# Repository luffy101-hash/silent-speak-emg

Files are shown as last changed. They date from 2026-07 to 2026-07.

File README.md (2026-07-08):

# SpeakEMG

> Silent-speech interface using multichannel surface EMG in over-ear headphones.

**Demo:** [luffy101-hash.github.io/SpeakEMG](https://luffy101-hash.github.io/SpeakEMG/) — interactive EMG simulator + command classifier

## What is this?

SpeakEMG reads facial and jaw muscle activity through four Grove EMG sensors mounted in headphone earmuffs. When you mouth words without sound, an ESP32-S3 streams 4-channel EMG data to a laptop, a 1D CNN classifies 3-second windows into one of 10 commands, and a companion app displays the result with text-to-speech.

Inspired by Tang et al., *IEEE TIM* 2025 (arXiv:2504.13921)

## Features

- 4-channel sEMG acquisition at 1000 Hz (ESP32-S3)
- 20 to 450 Hz Butterworth bandpass filtering
- 1D CNN classifier (10 silent commands)
- Real-time inference + TTS companion app
- Bench mode (USB serial) and wearable mode (Wi-Fi UDP)

## Commands

| Open | Close | Start | Stop | Yes |
|---|---|---|---|-----|
| No | Next | Back | Okay | Cancel |

## Hardware design (PCB)

Custom KiCad PCB for the EMG front-end. Full CAD exports in [`CAD/`](CAD/):

| Schematic | PCB layout | 3D render |
|---|---|---|
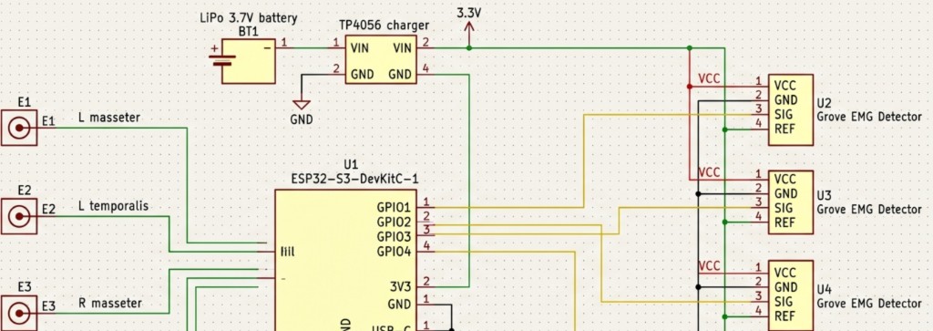
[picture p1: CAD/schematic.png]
Schematic
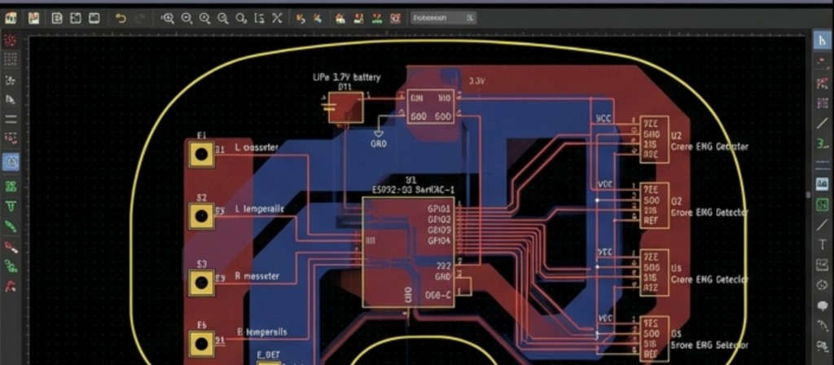
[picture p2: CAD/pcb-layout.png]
PCB layout
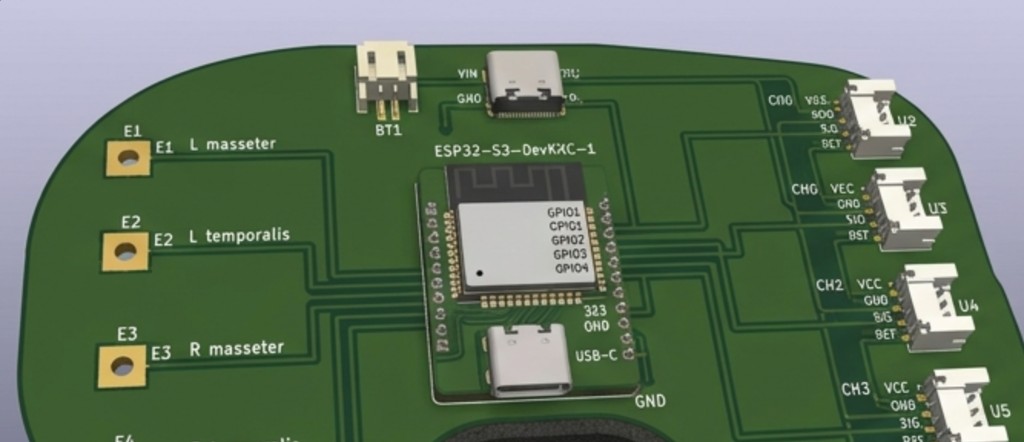
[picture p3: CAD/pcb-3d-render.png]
3D render
|  |  |  |

## BOM

Download [BOM.csv](BOM.csv). Columns: Component, Qty, Price_USD, Link, Phase.

## Wiring

| EMG # | Position | ESP32-S3 GPIO |
|---|---|---|
| 1 | Left earmuff - masseter | GPIO 1 |
| 2 | Left earmuff - temporalis | GPIO 2 |
| 3 | Right earmuff - masseter | GPIO 3 |
| 4 | Right earmuff - temporalis | GPIO 4 |

See [docs/wiring.md](docs/wiring.md) for Grove pinout and bench-test setup.

## Quick start

### Demo site (GitHub Pages)

Static demo lives in [`docs/`](docs/). Enable once in the repo:

**Settings → Pages → Build from branch `main` → folder `/docs`**

Live URL: `https://luffy101-hash.github.io/SpeakEMG/`

### Firmware

1. Open `firmware/emg_streamer/emg_streamer.ino` in Arduino IDE.
2. Board: **ESP32S3 Dev Module**. USB CDC on boot: enabled.
3. Flash. Open Serial Monitor at **115200** baud.
4. CSV output: `timestamp_ms,ch0,ch1,ch2,ch3`

Set `USE_WIFI 1` in the sketch for UDP streaming (configure `WIFI_SSID` / `WIFI_PASS`).

### App

```bash
streamlit run app/app.py
```

## Repo layout

```
SpeakEMG/
├── README.md
├── JOURNAL.md
├── BOM.csv
├── firmware/emg_streamer/
├── python/
├── app/
├── CAD/
└── docs/
```

## License

MIT. See [LICENSE](LICENSE).

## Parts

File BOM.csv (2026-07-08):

Component | Qty | Price_USD | Link | Phase
Grove EMG Detector | 4 | 112 | https://www.seeedstudio.com/Grove-EMG-Detector-p-1737.html | 1
ESP32-S3-DevKitC-1-N16R8 | 1 | 13 | https://www.amazon.com/gp/product/B0FPLVCTQD/ref=ox_sc_act_title_3?smid=A3EUM5QJ0XFZ3D&psc=1 | 1
Grove male jumper cables (5-pack) | 1 | 2 | https://www.seeedstudio.com/Grove-4-pin-Male-Jumper-to-Grove-4-pin-Conversion-Cable-5-PCs-per-Pack.html | 1
USB-C cable | 1 | 7 | https://www.sparkfun.com/products/15092 | 1
Breadboard | 1 | 8 | https://www.sparkfun.com/breadboard-full-size-bare.html | 1
Jumper wires (40-pack) | 1 | 4 | https://www.amazon.com/gp/product/B0BRTJQZRD/ref=ox_sc_act_title_2?smid=A2XLLJ8HYD6SMA&psc=1 | 1
Over-ear headphones | 1 | 23 | https://www.amazon.com/gp/product/B0CFGVDDH6/ref=ox_sc_act_title_1?smid=A148YQ9DI89PLZ&psc=1 | 2
LiPo 3.7V 500mAh | 1 | 8 | https://www.adafruit.com/product/1578 | 2
LiPo charger (USB-C) | 1 | 6 | https://www.adafruit.com/product/4410 | 2
Snap electrodes (10-pack) | 2 | 20 | https://www.amazon.com/gp/product/B01BLY2FK6/ref=ox_sc_act_title_5?smid=A49XZSPG2WVN&psc=1 | 2
Adhesive foam mounting squares | 1 | 6 | https://www.amazon.com/gp/product/B0CZL272TN/ref=ox_sc_act_title_4?smid=A33G03RGL0O2XH&psc=1 | 2
Velcro cinch straps (1 in) | 1 | 11 | https://www.homedepot.com/p/VELCRO-Eco-Wrap-EM-10-ft-x-1-in-Straps-in-Black-VEL-30188-USA/316765659 | 2

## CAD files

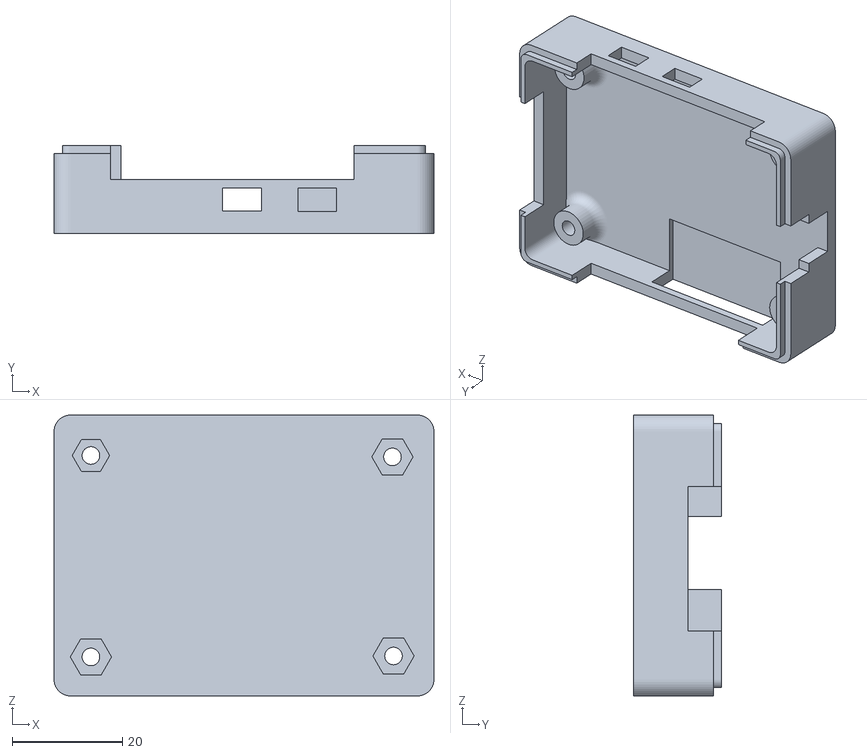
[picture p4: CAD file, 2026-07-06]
CAD/elektor-expansion-board/enclosure-bottom.stl
69.0 x 16.0 x 51.0

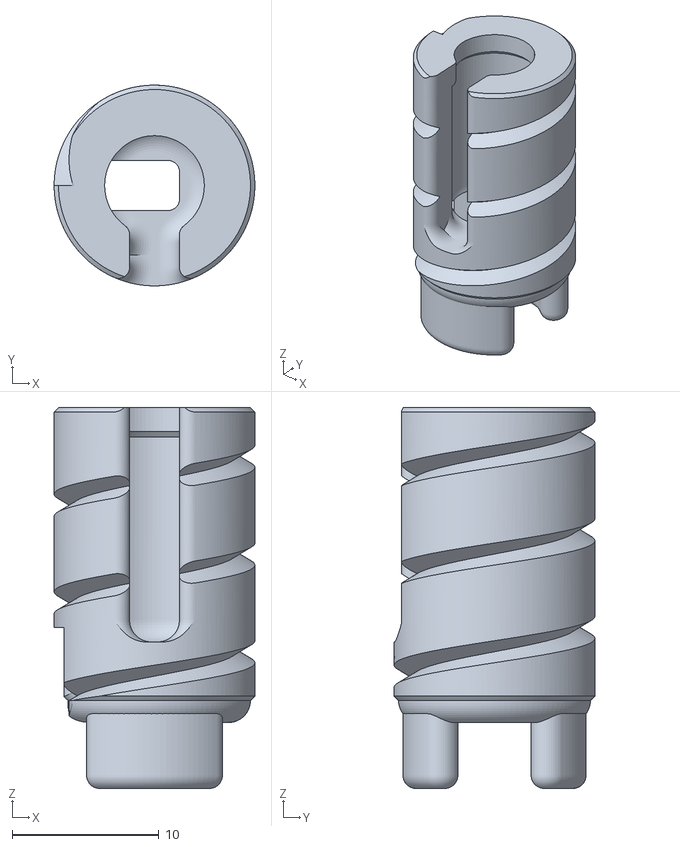
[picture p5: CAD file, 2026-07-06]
CAD/open-exg-headphones/Elec_Body_Short.stl
13.7 x 13.7 x 26.0

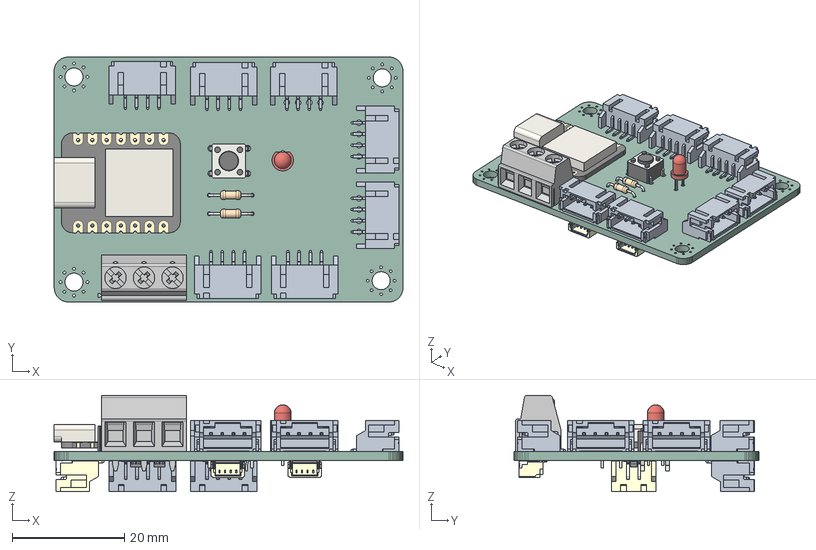
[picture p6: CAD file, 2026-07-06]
CAD/elektor-expansion-board/elektor-expansion-board-v1.0.step
62.2 x 43.7 x 17.2 mm
elektor-eXpansion-board-V1-0 PCB

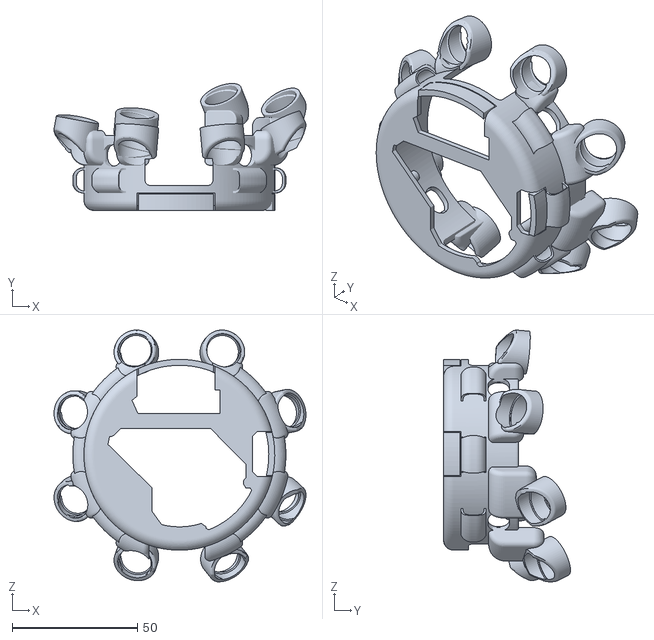
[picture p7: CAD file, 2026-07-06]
CAD/open-exg-headphones/Ear_Outer_Left.stl
100.5 x 50.7 x 100.5

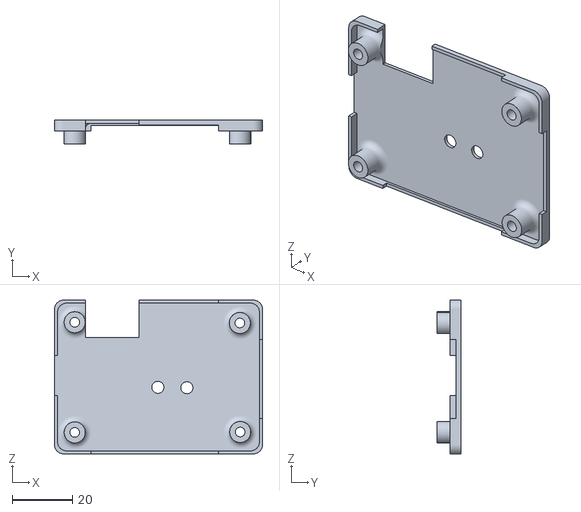
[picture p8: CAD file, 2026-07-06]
CAD/elektor-expansion-board/enclosure-top.stl
69.0 x 7.80 x 51.0

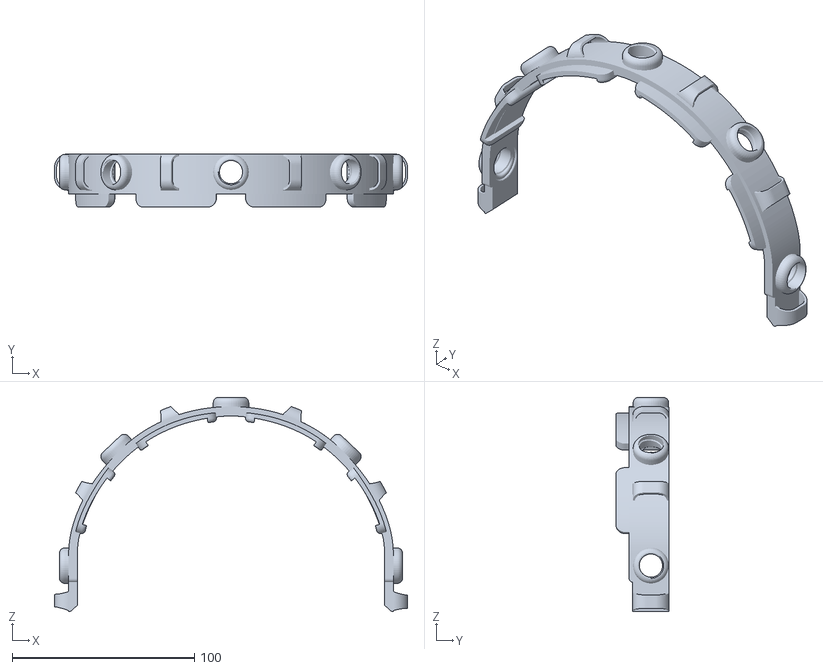
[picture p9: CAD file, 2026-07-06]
CAD/open-exg-headphones/Headband_Modular_Top.stl
193.6 x 29.3 x 117.5

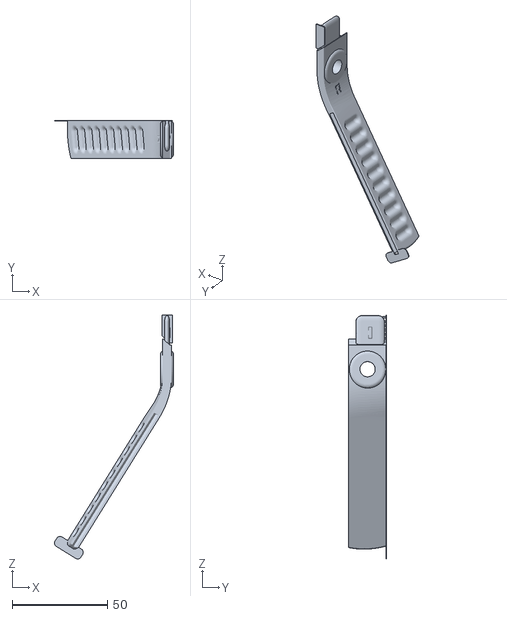
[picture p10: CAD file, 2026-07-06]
CAD/open-exg-headphones/Headband_Modular_Right.stl
62.4 x 20.0 x 127.9

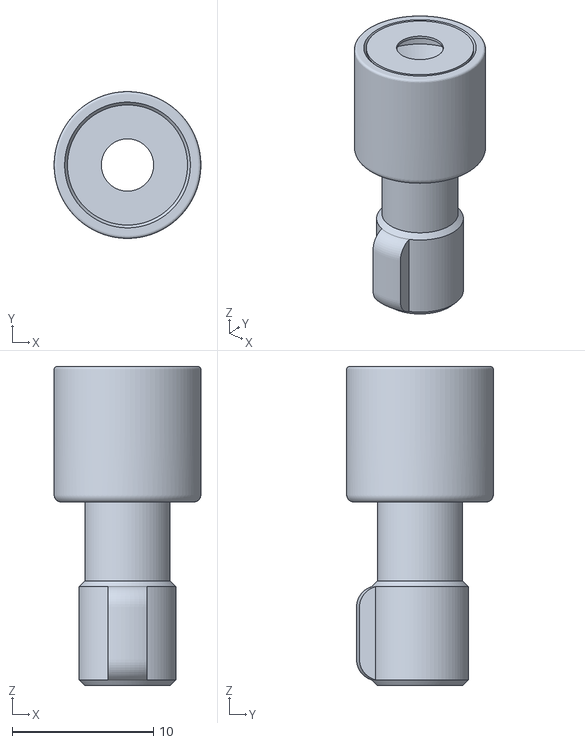
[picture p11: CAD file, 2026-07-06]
CAD/open-exg-headphones/Elec_Head.stl
10.4 x 10.4 x 22.6

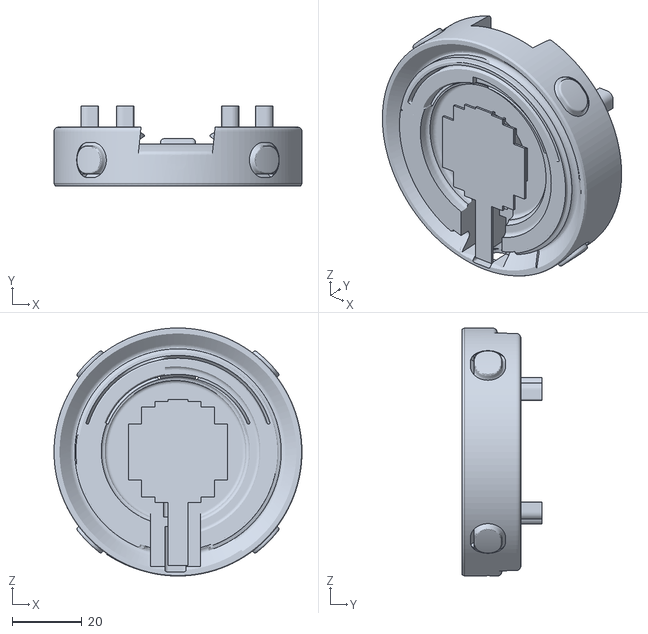
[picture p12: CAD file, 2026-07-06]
CAD/open-exg-headphones/Ear_Inner_Right.stl
71.0 x 22.8 x 71.0

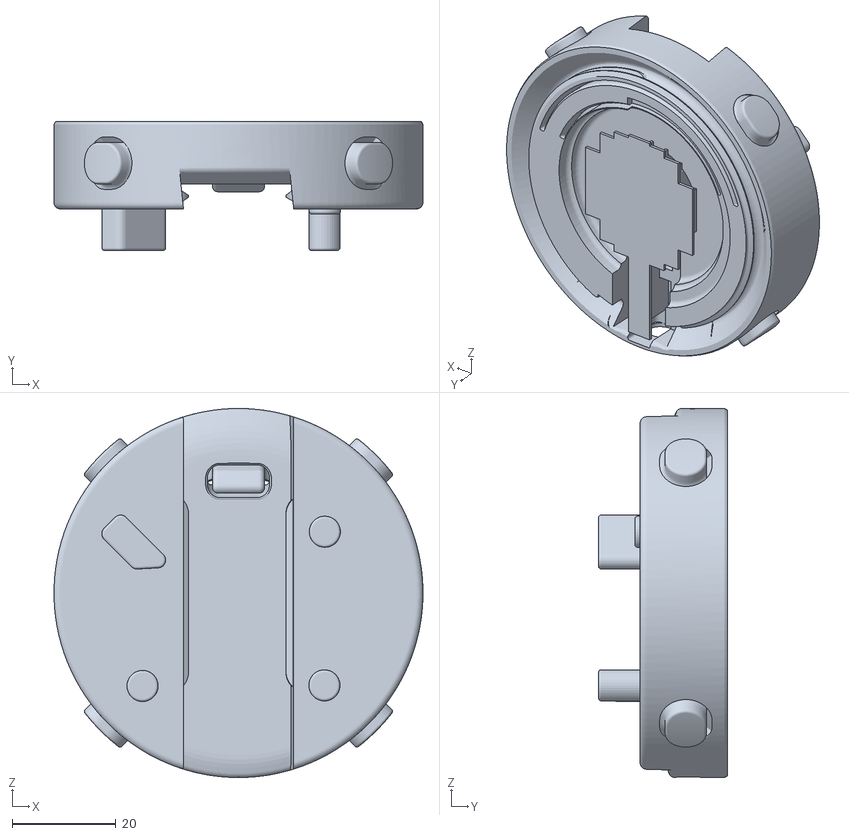
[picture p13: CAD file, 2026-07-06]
CAD/open-exg-headphones/Ear_Inner_Left.stl
71.0 x 24.8 x 71.0

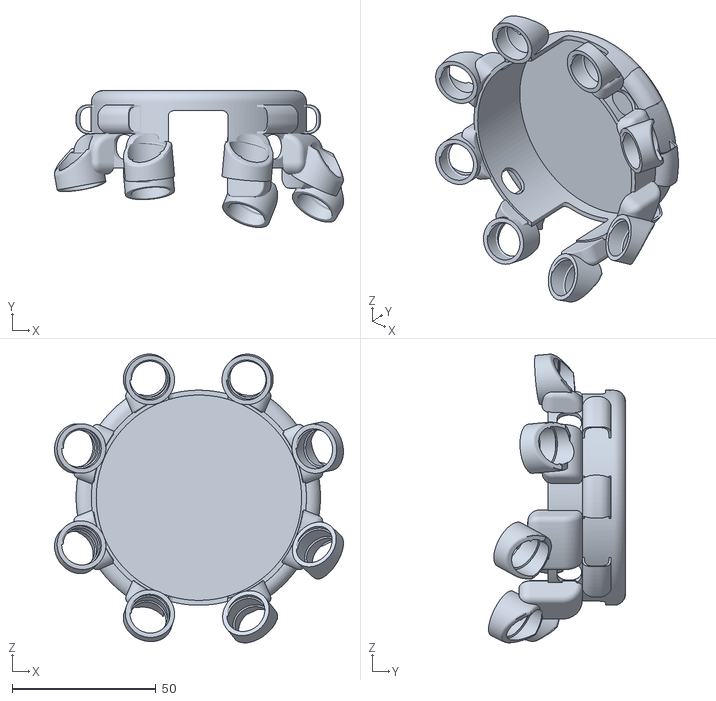
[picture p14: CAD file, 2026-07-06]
CAD/open-exg-headphones/Ear_Outer_Right.stl
100.5 x 47.7 x 100.4

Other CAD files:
CAD/open-exg-headphones/Headband_Modular_Left.stl

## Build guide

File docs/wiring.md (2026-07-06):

# Wiring

## Grove EMG → ESP32-S3 DevKitC-1

| Grove EMG | Wire | ESP32-S3 |
|---|---|---|
| VCC (red) | 3.3V | 3V3 |
| GND (black) | GND | GND |
| SIG (yellow) | analog | GPIO 1 to 4 |

Use separate Grove boards for channels 1 to 4 on GPIO 1, 2, 3, 4.

## Electrodes

- **Masseter:** lower-rear inside each earmuff (jaw clench)
- **Temporalis:** upper inside each earmuff (temple)
- **Reference:** earlobe clip, shared across all boards

## Bench test without headphones

Tape electrodes to jaw/cheek, reference on earlobe, run USB serial to laptop.

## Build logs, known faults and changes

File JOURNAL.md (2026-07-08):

# SpeakEMG Journal

Total time: about 28 hours

## June 21, 2026

- 11:40 AM to 1:35 PM
- found a paper about reading jaw muscles through emg sensors in headphones
- decided to build a silent-speech EMG interface from the paper
- looked up grove emg boards and esp32-s3 on seeed and amazon

## June 22, 2026

- 1:34 PM to 3:28 PM
- read more of the paper
- wrote down the 10 commands
- started a parts list on paper

commands i picked:

```
Open, Close, Start, Stop, Yes, No, Next, Back, Okay, Cancel
```

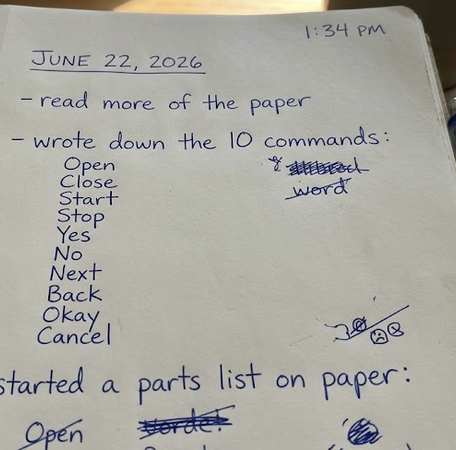
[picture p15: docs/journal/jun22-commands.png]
command list notes


## June 23, 2026

- 7:20 PM to 9:05 PM
- checked prices for grove emg detectors and esp32 board
- wrote BOM.csv with parts list
- figured out gpio pins for the four emg channels

pin map:

```
ch0 -> GPIO 1 (left masseter)
ch1 -> GPIO 2 (left temporalis)
ch2 -> GPIO 3 (right masseter)
ch3 -> GPIO 4 (right temporalis)
```

## June 24, 2026

- 4:10 PM to 5:55 PM
- sketched out the four parts of the system (sensors, esp32, laptop, app)
- started kicad schematic for the emg carrier pcb
- wired esp32-s3 to four grove emg detector slots on paper

## June 25, 2026

- 10:15 AM to 12:00 PM
- finished kicad schematic (saved as CAD/schematic.png)
- wrote down electrode spots (masseter and temporalis in each earmuff)
- routed power and gnd for all four emg channels

## June 26, 2026

- 6:45 PM to 8:40 PM
- opened arduino ide and started emg_streamer.ino
- got analogRead working on one gpio pin
- printed test values to serial monitor

first test code:

```cpp
sampleBuffer[i] = analogRead(EMG_PINS[i]);
Serial.println(sampleBuffer[i]);
```

## June 27, 2026

- 2:05 PM to 3:50 PM
- added hardware timer so it samples at 1000 hz
- hooked up all 4 gpio pins
- got csv output on serial: timestamp_ms,ch0,ch1,ch2,ch3

timer setup:

```cpp
static const int SAMPLE_RATE_HZ = 1000;
static const int EMG_PINS[4] = {1, 2, 3, 4};
```

sample lines from serial monitor:

```
142087,2048,2051,2049,2050
142088,2102,2047,2055,2048
142089,2098,2050,2052,2046
```

## June 28, 2026

- 9:40 AM to 11:30 AM
- added wifi and udp mode to the firmware for later
- left USE_WIFI at 0 for now since i will test over usb first
- cant test real emg yet because boards are not here

wifi flag in sketch:

```cpp
#define USE_WIFI 0
// set to 1 later for udp streaming
```

## June 29, 2026

- 3:15 PM to 5:10 PM
- started the python side
- wrote config.py for sample rate and window size (3 seconds)
- wrote preprocess.py with butterworth bandpass filter 20 to 450 hz

config values:

```python
SAMPLE_RATE_HZ = 1000
WINDOW_SEC = 3.0
BANDPASS_LOW_HZ = 20.0
BANDPASS_HIGH_HZ = 450.0
```

## June 30, 2026

- 8:00 PM to 9:50 PM
- built model.py with a 1d cnn called EMGNet
- tested it on random fake data to make sure input and output shapes work
- four channels in, 10 command classes out

model shapes:

```python
# input: (batch, 4 channels, 3000 samples)
# output: (batch, 10 classes)
```

ran a quick test:

```
>>> x = torch.randn(2, 4, 3000)
>>> y = model(x)
>>> y.shape
torch.Size([2, 10])
```

## July 1, 2026

- 1:50 PM to 3:45 PM
- wrote train.py, can train on synthetic data for now
- wrote record.py to save labeled windows from serial port
- made requirements.txt

train command:

```
python train.py --synthetic --epochs 10
```

example output:

```
epoch 1/10  loss=2.31
epoch 5/10  loss=1.04
epoch 10/10 loss=0.42
saved model to data/models/speahemg.pt
```

## July 2, 2026

- 7:30 PM to 9:20 PM
- wrote inference.py for live classification
- wrote receiver.py for reading serial stream
- got the classify loop working with fake data

fake inference output:

```
predicted: Open  (0.82)
predicted: Stop  (0.71)
predicted: Yes   (0.65)
```

## July 3, 2026

- 11:10 AM to 12:55 PM
- made streamlit app in app/app.py (shows commands and model status)
- wrote docs/wiring.md for how to hook up grove boards
- built pcb layout in kicad and exported CAD/pcb-layout.png
- did 3d render of the board (CAD/pcb-3d-render.png)

## July 4, 2026

- 10:00 AM to 12:00 PM
- wrote README and added LICENSE and .gitignore
- put the whole repo together and committed it
- next: order phase 1 parts, flash esp32, check jaw signal on one channel

repo layout:

```
SpeakEMG/
  firmware/emg_streamer/
  python/
  app/
  docs/
```

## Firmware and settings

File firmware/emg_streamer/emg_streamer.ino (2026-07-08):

/*
 * SpeakEMG: 4-channel Grove EMG streamer for ESP32-S3
 *
 * Samples 4 analog channels at SAMPLE_RATE_HZ and outputs CSV:
 *   timestamp_ms,ch0,ch1,ch2,ch3
 *
 * Grove EMG SIG pins -> GPIO 1, 2, 3, 4 (ADC1)
 * Reference electrode on earlobe -> Grove REF/GND
 */

#define USE_WIFI 0

#if USE_WIFI
#include <WiFi.h>
#include <WiFiUdp.h>
const char *WIFI_SSID = "YOUR_SSID";
const char *WIFI_PASS = "YOUR_PASSWORD";
const uint16_t UDP_PORT = 5005;
const char *UDP_HOST = "192.168.1.100";
WiFiUDP udp;
#endif

static const int EMG_PINS[4] = {1, 2, 3, 4};
static const int NUM_CHANNELS = 4;
static const int SAMPLE_RATE_HZ = 1000;
static const int ADC_BITS = 12;
static const int ADC_MAX = 4095;

hw_timer_t *sampleTimer = nullptr;
portMUX_TYPE timerMux = portMUX_INITIALIZER_UNLOCKED;

volatile bool sampleReady = false;
uint16_t sampleBuffer[NUM_CHANNELS];

void IRAM_ATTR onSampleTimer() {
  portENTER_CRITICAL_ISR(&timerMux);
  sampleReady = true;
  portEXIT_CRITICAL_ISR(&timerMux);
}

void readAdcChannels() {
  for (int i = 0; i < NUM_CHANNELS; i++) {
    sampleBuffer[i] = analogRead(EMG_PINS[i]);
  }
}

void emitSampleCsv(unsigned long timestampMs) {
  Serial.print(timestampMs);
  for (int i = 0; i < NUM_CHANNELS; i++) {
    Serial.print(',');
    Serial.print(sampleBuffer[i]);
  }
  Serial.println();
}

#if USE_WIFI
void emitSampleUdp(unsigned long timestampMs) {
  char line[64];
  int n = snprintf(line, sizeof(line), "%lu,%u,%u,%u,%u",
                   timestampMs,
                   sampleBuffer[0], sampleBuffer[1],
                   sampleBuffer[2], sampleBuffer[3]);
  udp.beginPacket(UDP_HOST, UDP_PORT);
  udp.write((const uint8_t *)line, n);
  udp.endPacket();
}
#endif

void setupAdc() {
  analogReadResolution(ADC_BITS);
  for (int i = 0; i < NUM_CHANNELS; i++) {
    pinMode(EMG_PINS[i], INPUT);
  }
}

void setupTimer() {
  sampleTimer = timerBegin(1000000);
  timerAttachInterrupt(sampleTimer, &onSampleTimer);
  timerAlarm(sampleTimer, 1000000 / SAMPLE_RATE_HZ, true, 0);
}

void setup() {
  Serial.begin(115200);
  while (!Serial && millis() < 3000) {
    delay(10);
  }

  setupAdc();
  setupTimer();

#if USE_WIFI
  WiFi.mode(WIFI_STA);
  WiFi.begin(WIFI_SSID, WIFI_PASS);
  while (WiFi.status() != WL_CONNECTED) {
    delay(500);
  }
  udp.begin(UDP_PORT);
  Serial.println("# wifi_connected");
#endif

  Serial.println("# speahemg_v1");
  Serial.println("# format: timestamp_ms,ch0,ch1,ch2,ch3");
}

void loop() {
  if (!sampleReady) {
    return;
  }

  portENTER_CRITICAL(&timerMux);
  sampleReady = false;
  portEXIT_CRITICAL(&timerMux);

  readAdcChannels();
  unsigned long t = millis();
  emitSampleCsv(t);

#if USE_WIFI
  emitSampleUdp(t);
#endif
}

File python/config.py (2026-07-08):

"""Shared constants for SpeakEMG pipeline."""

from pathlib import Path

ROOT = Path(__file__).resolve().parent.parent
DATA_DIR = ROOT / "data"
RAW_DIR = DATA_DIR / "raw"
MODEL_DIR = DATA_DIR / "models"

SAMPLE_RATE_HZ = 1000
WINDOW_SEC = 3.0
WINDOW_SAMPLES = int(SAMPLE_RATE_HZ * WINDOW_SEC)
HOP_SAMPLES = WINDOW_SAMPLES // 2  # 50% overlap

NUM_CHANNELS = 4
BANDPASS_LOW_HZ = 20.0
BANDPASS_HIGH_HZ = 450.0
BANDPASS_ORDER = 4

COMMANDS = [
    "Open",
    "Close",
    "Start",
    "Stop",
    "Yes",
    "No",
    "Next",
    "Back",
    "Okay",
    "Cancel",
]

NUM_CLASSES = len(COMMANDS)
COMMAND_TO_IDX = {name: i for i, name in enumerate(COMMANDS)}

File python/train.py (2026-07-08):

"""Train EMGNet on recorded or synthetic windows."""

from __future__ import annotations

import argparse
from pathlib import Path

import numpy as np
import torch
import torch.nn as nn
from torch.utils.data import DataLoader, TensorDataset

from config import COMMAND_TO_IDX, COMMANDS, MODEL_DIR, NUM_CHANNELS, RAW_DIR
from model import EMGNet, save_model
from preprocess import bandpass_filter, sliding_windows, synthetic_emg


def load_recordings(data_dir: Path) -> tuple[np.ndarray, np.ndarray]:
    """Load .npy files named {label}_{session}.npy with shape (n_samples, 4)."""
    xs, ys = [], []
    for path in sorted(data_dir.glob("*.npy")):
        label = path.stem.split("_")[0]
        if label not in COMMAND_TO_IDX:
            continue
        raw = np.load(path)
        filtered = bandpass_filter(raw)
        windows = sliding_windows(filtered)
        if len(windows) == 0:
            continue
        xs.append(windows)
        ys.append(np.full(len(windows), COMMAND_TO_IDX[label], dtype=np.int64))
    if not xs:
        return np.empty((0, NUM_CHANNELS, 0)), np.empty(0, dtype=np.int64)
    return np.concatenate(xs, axis=0), np.concatenate(ys, axis=0)


def build_synthetic_dataset(
    reps_per_class: int = 20, seed: int = 42
) -> tuple[np.ndarray, np.ndarray]:
    """Fallback dataset when no hardware recordings exist yet."""
    xs, ys = [], []
    for idx, _name in enumerate(COMMANDS):
        for rep in range(reps_per_class):
            raw = synthetic_emg(class_idx=idx, seed=seed + idx * 100 + rep)
            filtered = bandpass_filter(raw)
            windows = sliding_windows(filtered)
            if len(windows) == 0:
                continue
            xs.append(windows)
            ys.append(np.full(len(windows), idx, dtype=np.int64))
    return np.concatenate(xs, axis=0), np.concatenate(ys, axis=0)


def train(
    X: np.ndarray,
    y: np.ndarray,
    epochs: int = 50,
    batch_size: int = 16,
    lr: float = 1e-3,
    device: str = "cpu",
) -> EMGNet:
    X_t = torch.tensor(X, dtype=torch.float32)
    y_t = torch.tensor(y, dtype=torch.long)
    loader = DataLoader(TensorDataset(X_t, y_t), batch_size=batch_size, shuffle=True)

    model = EMGNet().to(device)
    opt = torch.optim.Adam(model.parameters(), lr=lr)
    loss_fn = nn.CrossEntropyLoss()

    model.train()
    for epoch in range(1, epochs + 1):
        total_loss = 0.0
        correct = 0
        total = 0
        for xb, yb in loader:
            xb, yb = xb.to(device), yb.to(device)
            opt.zero_grad()
            logits = model(xb)
            loss = loss_fn(logits, yb)
            loss.backward()
            opt.step()
            total_loss += loss.item() * len(xb)
            correct += (logits.argmax(1) == yb).sum().item()
            total += len(xb)
        acc = correct / max(total, 1)
        print(f"epoch {epoch:03d}  loss={total_loss/total:.4f}  acc={acc:.3f}")

    return model


def main() -> None:
    parser = argparse.ArgumentParser(description="Train SpeakEMG EMGNet")
    parser.add_argument("--data-dir", type=Path, default=RAW_DIR)
    parser.add_argument("--epochs", type=int, default=50)
    parser.add_argument("--synthetic", action="store_true", help="Use fake EMG data")
    parser.add_argument("--out", type=Path, default=MODEL_DIR / "speahemg.pt")
    args = parser.parse_args()

    MODEL_DIR.mkdir(parents=True, exist_ok=True)

    if args.synthetic or not any(args.data_dir.glob("*.npy")):
        print("Training on synthetic EMG (no recordings found).")
        X, y = build_synthetic_dataset()
    else:
        print(f"Loading recordings from {args.data_dir}")
        X, y = load_recordings(args.data_dir)

    if len(X) == 0:
        raise SystemExit("No training windows. Record data or use --synthetic.")

    # 80/20 split
    n = len(X)
    idx = np.random.permutation(n)
    split = int(0.8 * n)
    train_idx, val_idx = idx[:split], idx[split:]
    model = train(X[train_idx], y[train_idx], epochs=args.epochs)

    model.eval()
    with torch.no_grad():
        val_x = torch.tensor(X[val_idx], dtype=torch.float32)
        val_y = torch.tensor(y[val_idx], dtype=torch.long)
        pred = model(val_x).argmax(1)
        val_acc = (pred == val_y).float().mean().item()
    print(f"validation accuracy: {val_acc:.3f}")

    save_model(model, str(args.out))
    print(f"saved model -> {args.out}")


if __name__ == "__main__":
    main()

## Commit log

2026-07-06 Address Outpost design review: CAD, BOM CSV, funding clarity
    Add KiCad PCB images, BOM.csv, simplified grant section in README,
    journal PCB entries, and remove project_spec.tex.
    [BOM.csv]
2026-07-06 Add reference CAD from Open ExG Headphones and Elektor board
    Include core earmuff, electrode, and headband STLs plus Elektor
    carrier STEP and enclosure files for Phase 2 mechanical design.
    [Ear_Inner_Left.stl, Ear_Inner_Right.stl, Ear_Outer_Left.stl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]
2026-07-06 Add purchase links to BOM.csv and setup-git hook script
    Fill in Amazon links for all BOM items and add setup-git.sh to
    install a prepare-commit-msg hook that strips Cursor co-author lines.
    [BOM.csv]
2026-07-06 Remove setup-git from repo; BOM links remain
    Git hook setup moved to local Cursor skill, not tracked in git.
2026-07-07 Replace broken Amazon BOM links with verified vendor URLs
    Use DigiKey, SparkFun, Adafruit, B&H, OpenBCI, and Home Depot links that actually resolve.
    [BOM.csv]
2026-07-08 Update BOM with verified Amazon purchase links and refresh project docs.
    Replace vendor links for ESP32, jumper wires, headphones, electrodes, and mounting squares with the selected Amazon listings.
    [BOM.csv]
